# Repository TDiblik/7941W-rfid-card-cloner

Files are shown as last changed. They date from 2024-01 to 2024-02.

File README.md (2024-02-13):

# RFID Card Cloning Device

- [Showcase](#showcase)
- [Prerequisites](#prerequisites)
- [What HW do I need?](#what-hw-do-i-need)
- [How does it work?](#how-does-it-work)
  - [After turning the device on](#after-turning-the-device-on)
  - [S mode](#s-mode)
  - [Z mode](#z-mode)
- [How to setup?](#how-to-setup)
- [Bitmap generator](#bitmap-generator)
- [Development notes](#development-notes)
- [Legal notice](#legal-notice)

# Showcase

Showcase gif

# Prerequisites

- Whenever the docs call something "a/the display", it means the 8x8 LED matrix
- Whenever the docs say "input", it means the Joystick, or selecting something with the Joystick
- Whenever the docs say "the menu", it means the 6 options (S1, S2, S3, Z1, Z2, Z3)
- Whenever the docs call something "a/the board", it means XIAO nRF52840
- The cloner supports 2 types of cards: 125KHz and 13.56MHz.
  - When referring to both, the docs say "type 1"
  - 125KHz is refferd to as "type 2"
  - 13.56MHz is refferd to as "type 3"
- All actions are tried **5 times** before failing. If you wish to change this behaviour, you can do so by changing `NUMBER_OF_EXECUTE_RETRIES` inside `./advanced/src/Menu.h`
- Code for the actual device is inside the `./advanced` folder and the resources for it are inside the `./resources` folder.
  - There is also the `./simple` folder. This was simply a test of mine (fully functional tho) before creating the final devices, to make sure that the 7941W is working as expected. If you want to just clone cards at home, wire it based on the `./simple/wiring.jpg` and upload the code using Platformio VSCode.

# What HW do I need?

1. Seeed Studio XIAO nRF52840
2. 7941W dual-frequency reader-writer
3. A Joystick
4. Adafruit Mini 8x8 LED Matrix w/I2C Backpack
5. A ON/OFF switch
6. 4 AAA battery case
7. Clear, writeable 125KHz (usually labeled EM4305/T5577) and 13.56MHz cards (for example Mifare 1k S50)

# How does it work?

Wire schematic<br/>
The heart component that allows this to work is the `7941W Dual-Frequency Card Reader/Writer`, which is controlled by the board using [the manufacturer's protocol over UART](https://www.icstation.com/dual-frequency-rfid-reader-writer-wireless-module-uart-1356mhz-125khz-icid-card-p-12444.html). <!-- I was unable to find docs, and the website I linked was used as a reference during the development --> This component does the whole "reading an ID" and "writing an ID" part of the device. <br />
However, as a user, you don't really care about that. (if you indeed care more about that tho, browse the source code, it's not that complicated `cat src/* | wc -l => 788`) <br />

## After turning the device on

If you're running in DEBUG mode (variable `DEBUG` inside `./advanced/src/debug.h` is set to `true` at the time of compilation), you will **skip** the initial animation where two images appear on the display for 1.5s (both):

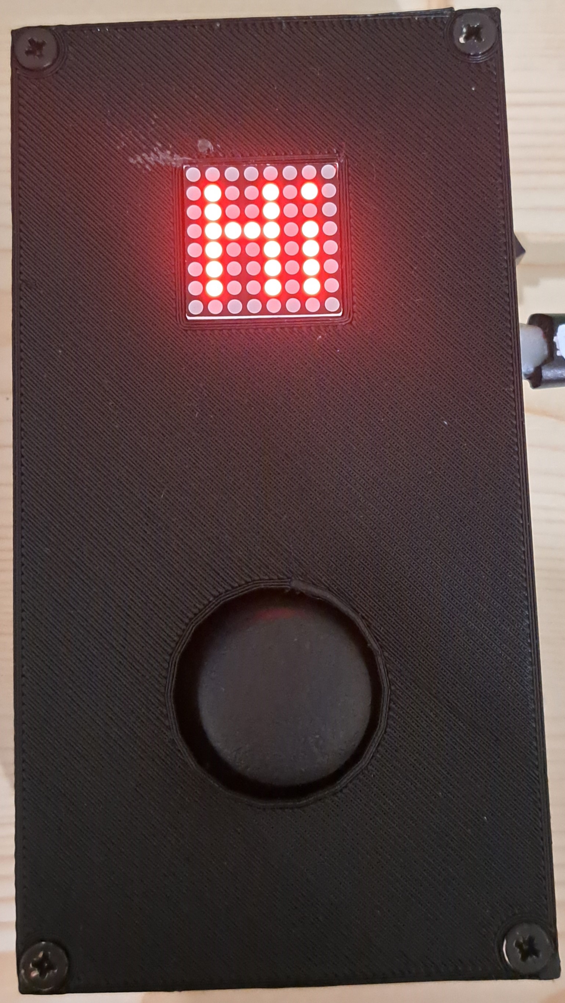
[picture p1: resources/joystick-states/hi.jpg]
Jostick state with HI written on the display

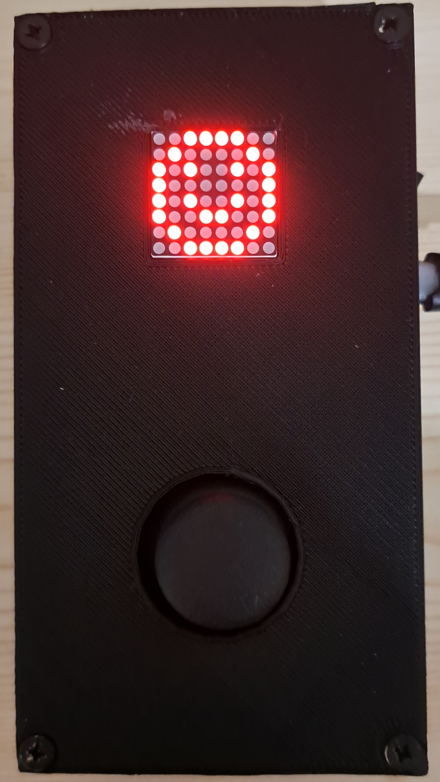
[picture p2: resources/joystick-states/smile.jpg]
Jostick state with smiley face on the display


After that, you will be put into the menu. This is the only way to control the device.
There are two main "modes". The S mode and Z mode. Both have 3 options. You can switch between the options and modes using the joystick (UP and DOWN movements) [if you're confused about the wiring, consult `./advanced/src/Joystick.cpp`].

## S mode

This mode is used for scanning cards. You can choose from one of 3 options (S1, S2, S3). <br/>
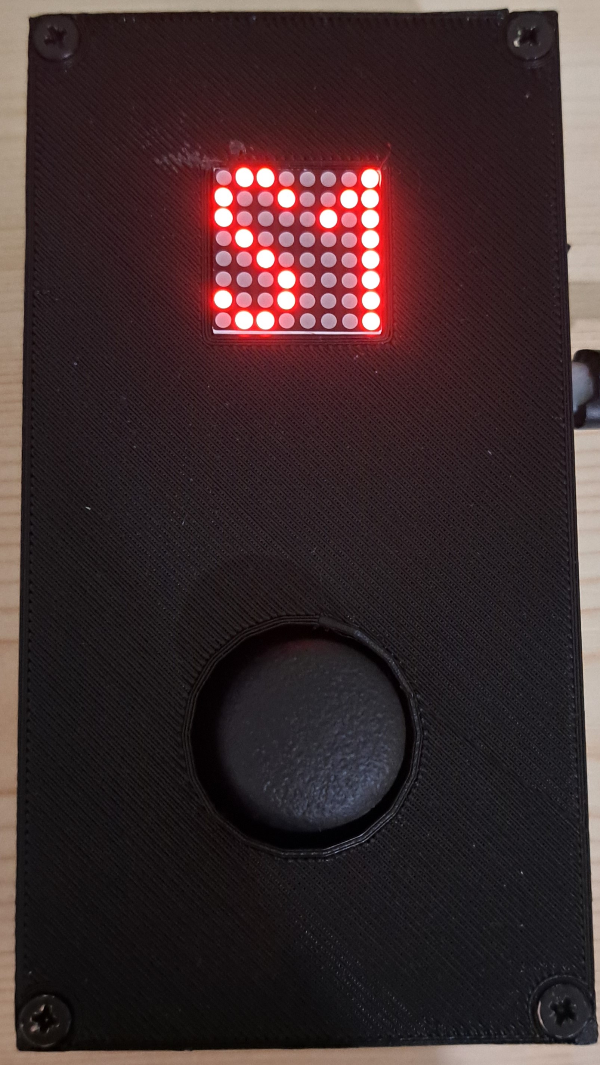
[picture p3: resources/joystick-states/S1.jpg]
Jostick state with S1 option selected

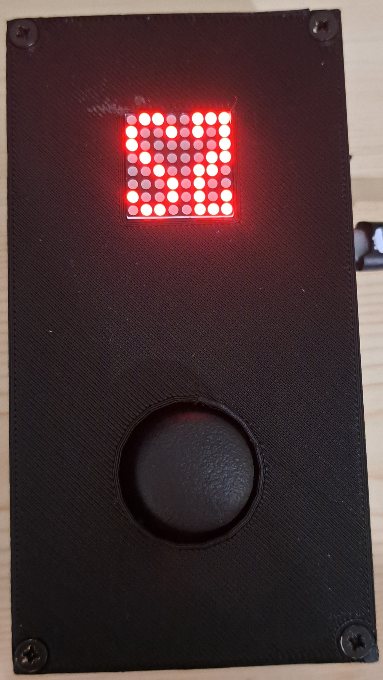
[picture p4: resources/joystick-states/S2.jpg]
Jostick state with S2 option selected

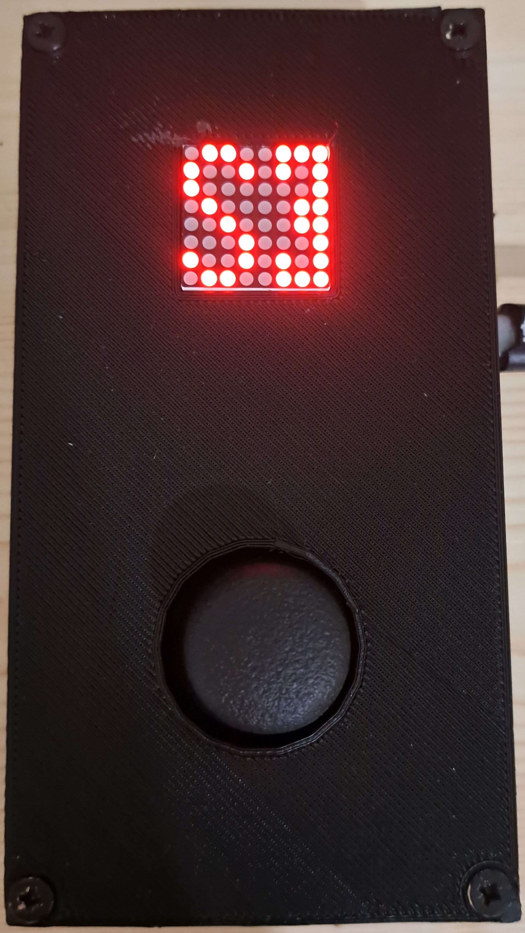
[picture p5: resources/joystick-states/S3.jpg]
Jostick state with S3 option selected
 <br/>
After you've selected the desired mode, place the card near the scanner (back of the device) and press down on the joystick. When the S mode succeeds, the card is remembered in RAM. When the S mode fails, nothing happens. The last remembered card is **always** the last successful scan result. After a successful scan, the result of the scan (image drawn to the display) stays there until a new input is registered. <br/>
As mentioned before, there are 3 options: <br/>

- S1: This mode works as S2 and S3 combined. It scans for both types of cards and then shows the results. Because of that, it has special success results. Other results are the same as for the S2 and S3 options (+ the number for which the result applies is shown after the result).
- S2: This mode scans only for the type 2 cards.
- S3: This mode scans only for the type 3 cards.

After each scan, there is a result shown. If the result **is not a Failure**, then the information (even if partial), gets stored in the device RAM. Even after a partial success (see below), you can still proceed to write this information onto your blank card (however it's probable that it won't work as expected). The results for **S2** and **S3** are as follows:

**Success:**
Everything went according to the plan: <br/>
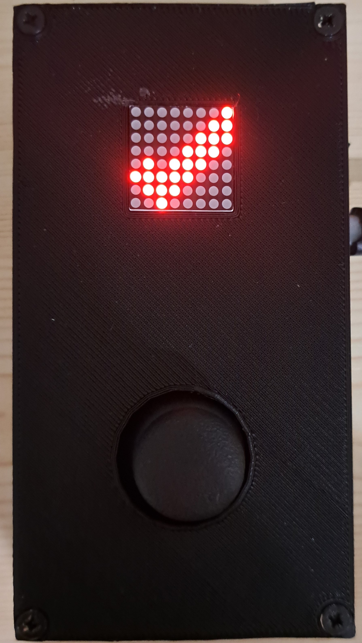
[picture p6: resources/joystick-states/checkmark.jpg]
Jostick state with checkmark on the display
 <br/>

**Undefined Response:**
There were errors while communicating with the cloning device. This can (for example) occur when there is not enough time for the card to be scanned: <br/>
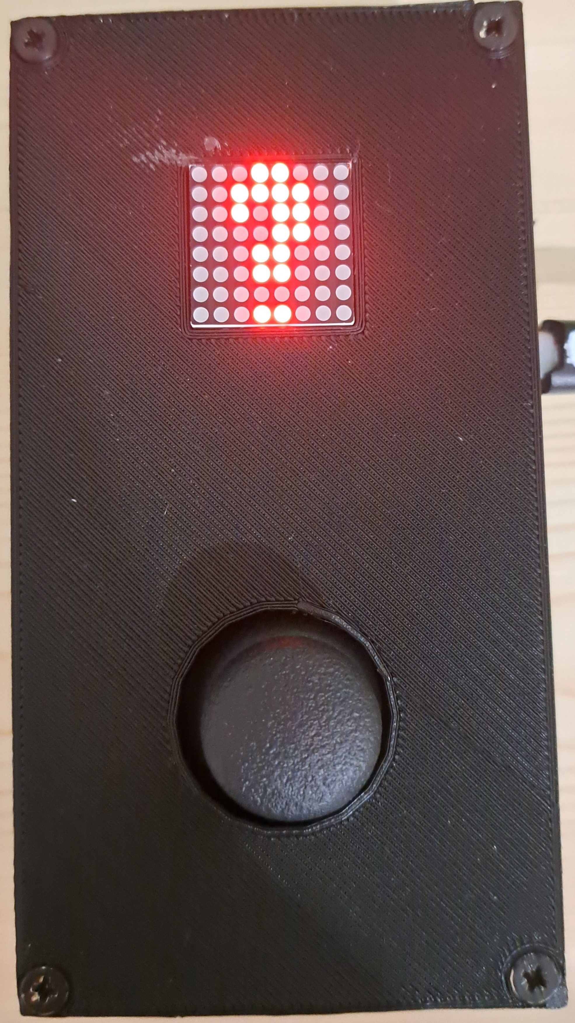
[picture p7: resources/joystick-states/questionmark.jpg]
Jostick state with questionmark on the display
 <br/>

**Invalid Checksum:**
The device sent back an ID, **however** the checksum of the message sent does not match the checksum calculated. This usually means that one or two of the bits of the ID received are not correct and there may have been some interference while receiving the data: <br/>
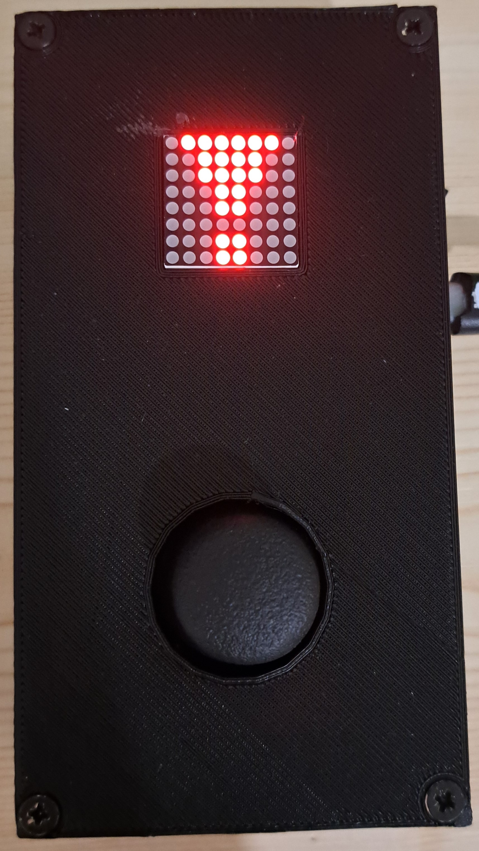
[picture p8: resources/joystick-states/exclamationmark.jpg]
Jostick state with exclamationmark on the display
 <br/>

**Failure:**
The action failed. Nothing is stored into the RAM. This can occur when there is no supported card to be read. <br/>
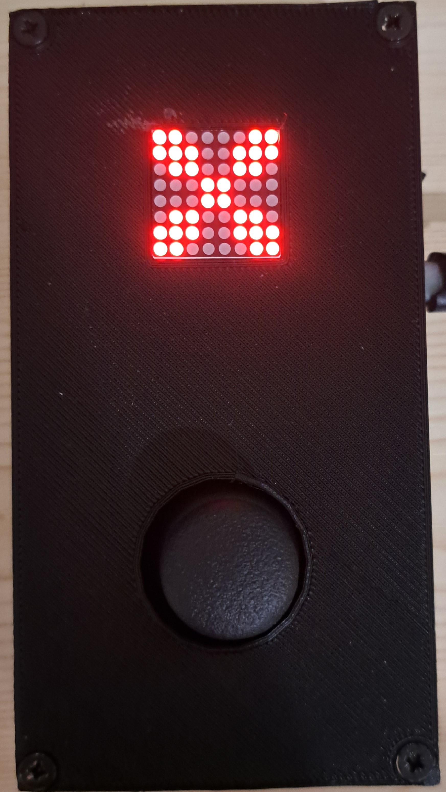
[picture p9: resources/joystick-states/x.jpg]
Jostick state with an X on the display
 <br/>

**S1 Success (type 1):** <br />
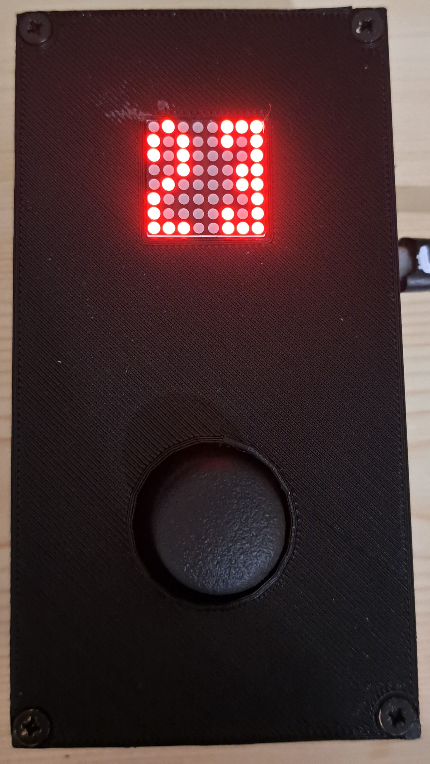
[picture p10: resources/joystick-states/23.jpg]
Jostick state with 23 written on the display
Jostick state with checkmark on the display <br />
Both the type 2 and type 3 cards were found and scanned. This can happen when one card supports multiple frequencies, or when multiple cards were placed near the scanner.

**S1 Success (type 2):** <br />
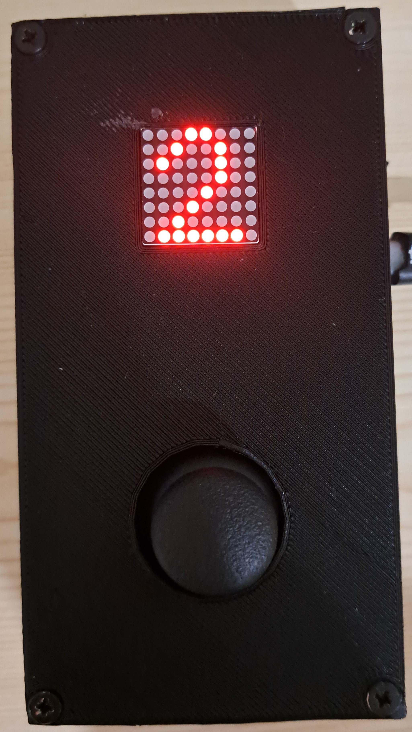
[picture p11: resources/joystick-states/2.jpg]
Jostick state with 2 written on the display
Jostick state with checkmark on the display <br />

**S1 Success (type 3):** <br />
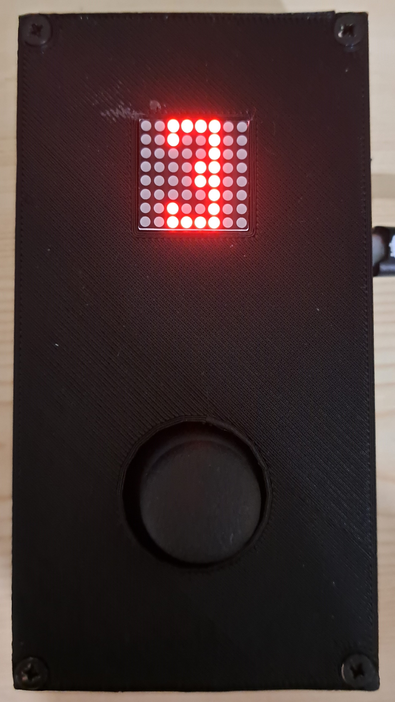
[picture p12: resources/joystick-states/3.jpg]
Jostick state with 3 written on the display
Jostick state with checkmark on the display <br />

## Z mode

This mode is used for writing scanned cards. You can choose from one of 3 options (Z1, Z2, Z3). <br/>
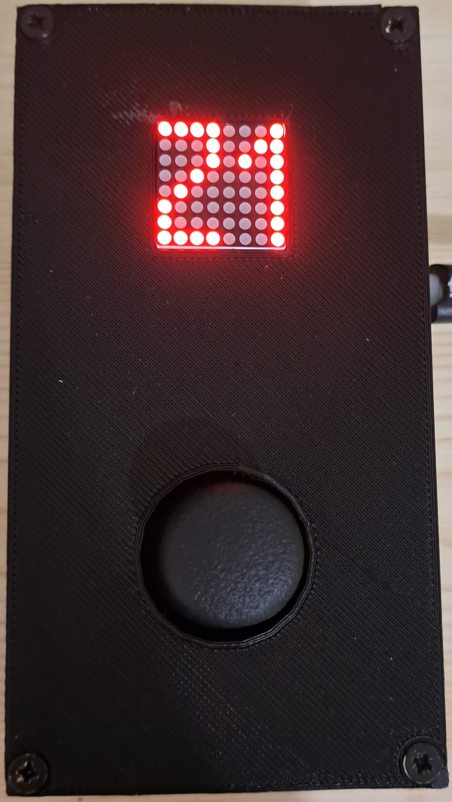
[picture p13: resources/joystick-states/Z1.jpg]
Jostick state with Z1 option selected

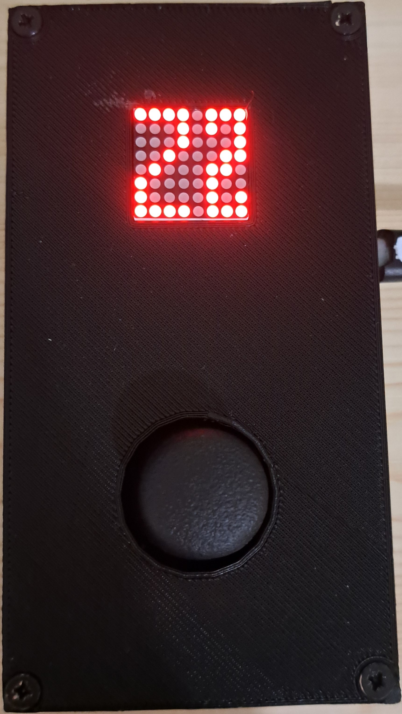
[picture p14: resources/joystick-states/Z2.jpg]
Jostick state with Z2 option selected

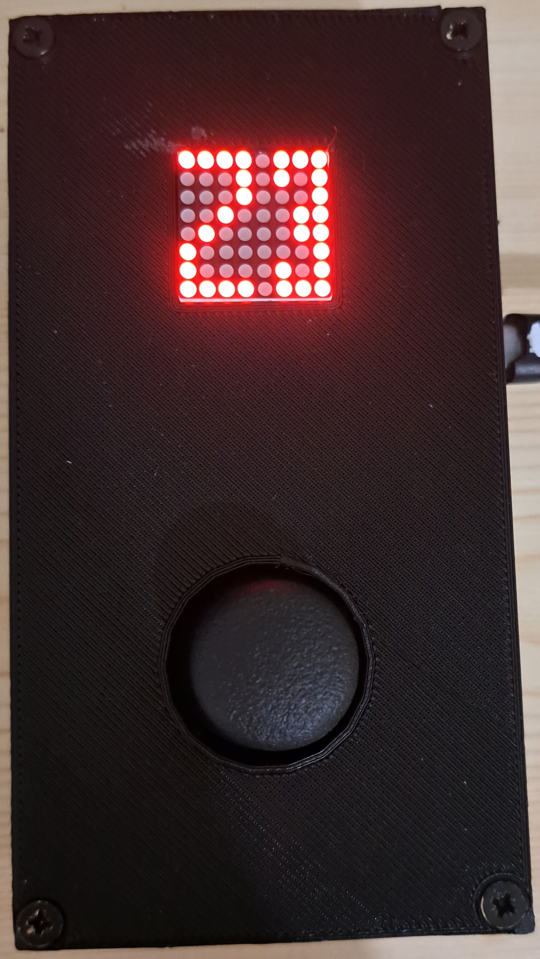
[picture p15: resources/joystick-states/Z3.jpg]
Jostick state with Z3 option selected
 <br/>
After you've read a card, you want to "clone it" onto your clear card. That's what these 3 modes are for. After you've selected one of the modes and pressed onto the joystick, there will be an action performed (based on the selection): <br/>

- Z1: This mode works as Z2 and Z3 combined. It tries to write onto both types of cards and then shows the results. Because of that, it has special success results. Other results are the same as for the Z2 and Z3 options.
- Z2: This mode tries to write onto the type 2 cards.
- Z3: This mode tries to write onto the type 3 cards.

Since the typical responses (Success, Undefined response, Invalid checksum, Failure,...) are the same for Z modes (and have the same implications, just replace "read" with "write" while reading them) as for the S modes, they are not included here. If you see them after using the Z mode, just consult the docs part above. <br/>
What is different, however, are the Z1 responses. After you try to write using Z1, there is always a type number flashed and the appropriate response for the card type (for example: "2 flashes with Failure and then 3 flashes with Success" -> This means that the device was unable to write onto type 2 card, however, it was able to write onto the type 3 card)
If you were to try to write before scanning any card, the following symbol will be shown, indicating that there is no card stored in the RAM. <br/>
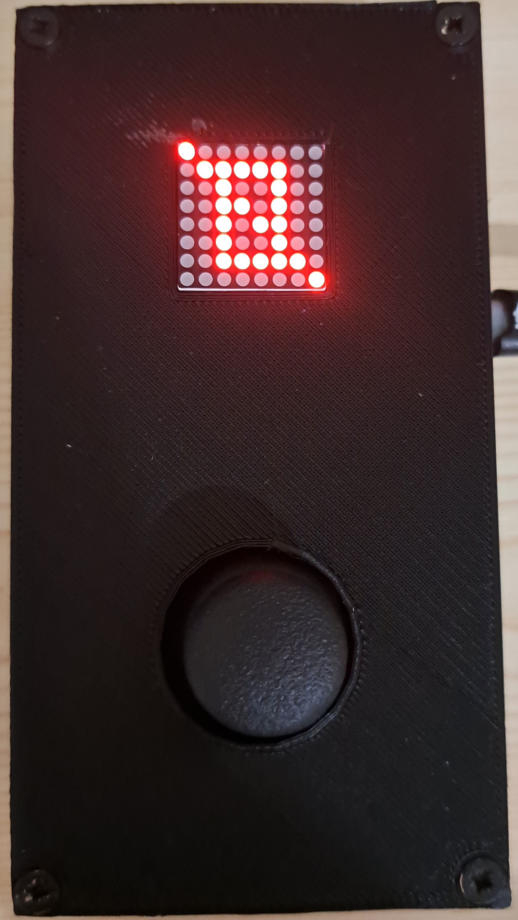
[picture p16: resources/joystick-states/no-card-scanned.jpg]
Jostick state with no-card-scanned symbol on the display


# How to setup?

1. Somehow connect the wires according to the schematic
2. Write a new version of the firmware onto the device (using Platformio and VSCode)
3. 3D print the case using the exported files provided `./resources/case-export` or edit/export them on your own with FreeCAD `./resources/case.FCStd`
4. Put electronics into the case
   - for the insides, use +-1.5mm radius screws
   - the battery holder should be placed in the lower part of the back case such that you can replace them from the other side.
   - 7941W should be screwed onto the two columns inside the "back part" of the case.
   - board should be placed onto the "holder" right above the 7941W and pointing outwards by the USB-C port.
   - you can probably guess how to screw in the joystick and display based on the design of the "top part" of the case.
5. Screw the case together (use at most 3mm radius screws)
6. Enjoy your device :)
7. If you find a bug, or have a problem with anything SW/HW related, [open an issue](https://github.com/TDiblik/7941W-rfid-card-cloner/issues), or shoot me an email

# Bitmap generator

You might notice, in the root of the project, there is a Python script called `bitmap_generator.py`. You can use this to generate bitmaps to draw onto the display. All you have to do is start the program `python bitmap_generator.py`. The following window will pop up: <br/>
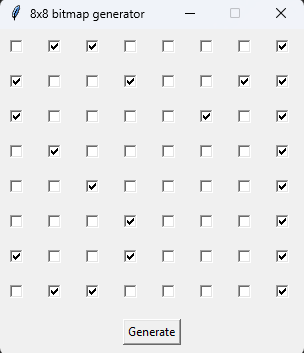
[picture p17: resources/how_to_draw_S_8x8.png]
Example usage of the bitmap generator to draw S1
 <br/>
Here, you can draw something that you want to get displayed on the screen. After you're done, hit the "Generate" button. This will output "C code" that you can put into the project. The output will look like this:

```cpp
static const uint8_t PROGMEM NAME_BITMAP[]
{ 0b01100001,
  0b10010011,
  0b10000101,
  0b01000001,
  0b00100001,
  0b00010001,
  0b10010001,
  0b01100001 };
```

If you pass this as an argument into the `LEDMatrix.draw` or `LEDMatrix.blink` functions, it will get drawn. You can quickly test it out by changing the `main.cpp` to the following:

```cpp
#include <Arduino.h>
#include <Wire.h>
#include <SPI.h>

#include "debug.h"
#include "LEDMatrix.h"

static LEDMatrix led_matrix = LEDMatrix();

// REPLACE THIS WITH YOUR GENERATED BITMAP
static const uint8_t PROGMEM YOUR_GENERATED_BITMAP[]
{ 0b00000000,
  0b01001010,
  0b01001000,
  0b01111010,
  0b01001010,
  0b01001010,
  0b01001010,
  0b00000000 };

void setup() {
  Serial.begin(9600);
  led_matrix.setup();
  debug_println("LED Matrix - done");
}

void loop() {
  led_matrix.draw(YOUR_GENERATED_BITMAP);
  delay(500); // we don't want to spam it... Tbh, the `.draw` could be in the setup function and the loop could be empty
}
```

# Development notes

1. Before pushing a release version of the firmware, make sure to change the `DEBUG` variable inside `./advanced/src/debug.h` to `false` at the time of compilation.
2. As a convention, all bitmaps are stored inside the `./advanced/src/LEDMatrix.h` and named in UPPERCASE.

# Legal notice

The code/device/files (further addressed as just "device") provided are for educational purposes only and should not be used for any malicious or illegal activities. Any unauthorized use of this device is strictly prohibited and violators will be held liable for their actions. The device is intended to be used solely for the purpose of learning and understanding vulnerabilities and should not be executed on any systems without proper authorization and oversight. The author of this device takes no responsibility for any actions taken by any party using this device and is not liable for any damages or harm caused as a result of its use.

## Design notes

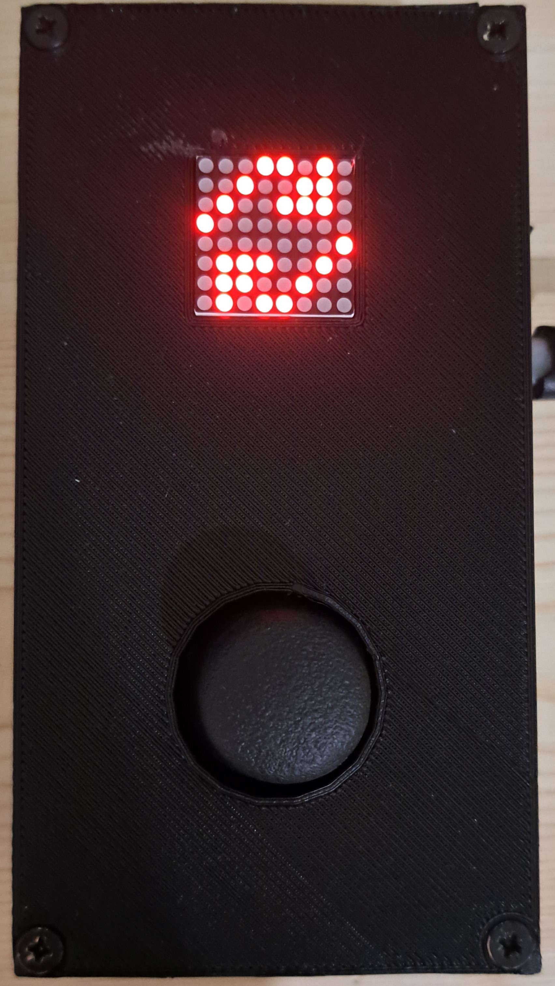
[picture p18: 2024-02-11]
resources/joystick-states/loading.jpg

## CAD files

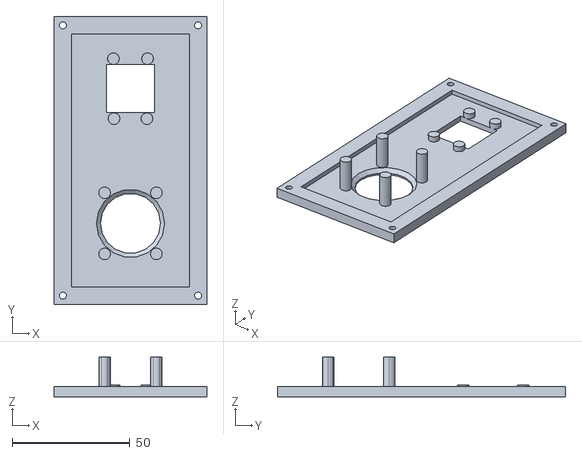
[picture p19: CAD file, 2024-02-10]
resources/case-export/front.obj
65.0 x 122.5 x 17.0

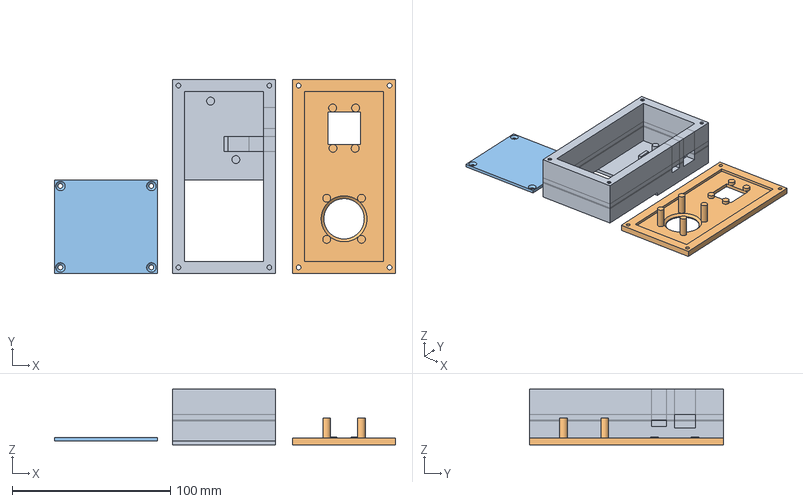
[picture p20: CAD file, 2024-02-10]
resources/case.FCStd
215.6 x 122.5 x 35.4 mm
back
front
closing

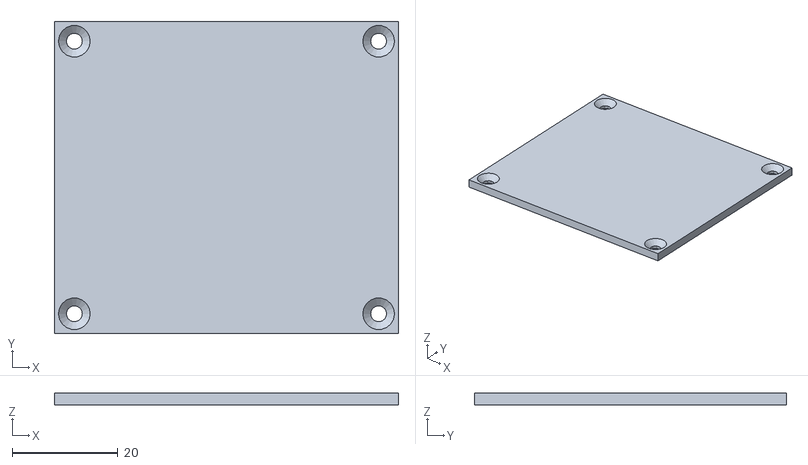
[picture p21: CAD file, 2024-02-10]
resources/case-export/closing.obj
65.0 x 59.0 x 2.25

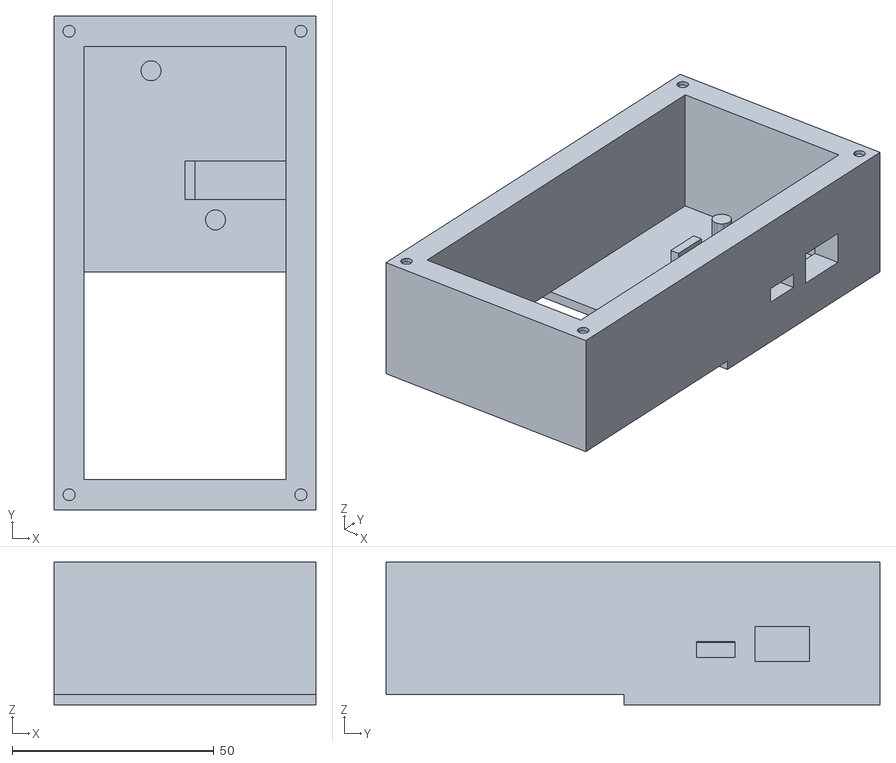
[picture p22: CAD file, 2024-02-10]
resources/case-export/back.obj
65.0 x 122.5 x 35.4

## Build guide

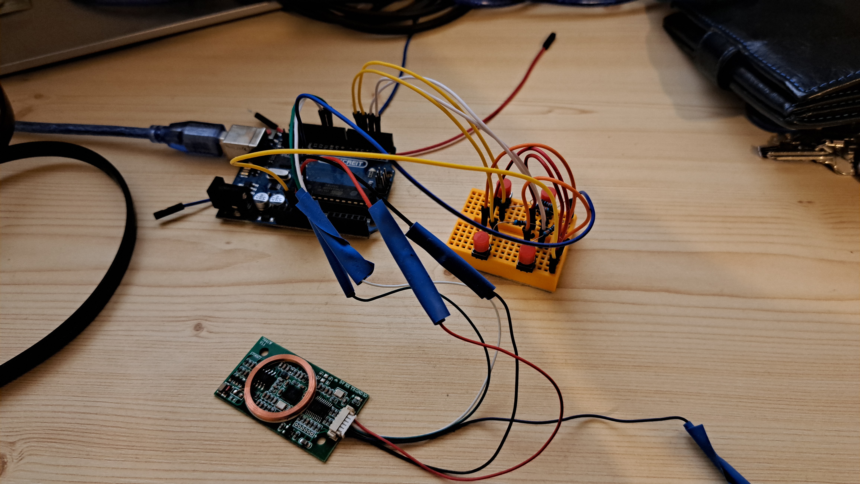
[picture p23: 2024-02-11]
simple/wiring.jpg

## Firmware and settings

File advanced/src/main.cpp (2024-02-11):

#include <Arduino.h>
#include <Wire.h>
#include <SPI.h>

#include "debug.h"
#include "Joystick.h"
#include "LEDMatrix.h"
#include "Menu.h"
#include "RFID.h"

static Joystick joystick = Joystick(D0, A1, A2);
static LEDMatrix led_matrix = LEDMatrix();
static RFID rfid = RFID(Serial1); // Connect RFID-RX->Board-D6 ; RFID-TX->Board-D7, refers to https://files.seeedstudio.com/wiki/XIAO-BLE/pinout2.png
static Menu menu = Menu(led_matrix, rfid);

void setup() {
  Serial.begin(9600); // always try to establish a connection (even in release mode), it's easier to flash new versions / diagnose errors this way

  debug_println("--- Setting up HW components ---");
  delay(500); // wait for a bit, just to make sure

  joystick.setup();
  debug_println("Joystick - done");

  led_matrix.setup();
  debug_println("LED Matrix - done");

  rfid.setup();
  debug_println("Communication with the cloner - done");

  debug_println("--- Finished setup successfully ---");
}

void loop() {
  menu.handle_input(joystick.get_status());
}

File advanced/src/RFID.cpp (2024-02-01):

#include "RFID.h"
#include "debug.h"

void RFID::setup() {
    this->_serial.begin(115200);
}

RFIDReadResult* RFID::read_id_125KHz() { return this->_read_id((uint8_t)0x15); };
RFIDReadResult* RFID::read_id_1356MHz() { return this->_read_id((uint8_t)0x10); };
RFIDResponse RFID::write_id_125KHz(RFIDReadResult* card_info) { return this->_write_id((uint8_t)0x16, card_info); };
RFIDResponse RFID::write_id_1356MHz(RFIDReadResult* card_info) { return this->_write_id((uint8_t)0x11, card_info); };

RFIDResponse RFID::_read_rw_response_into_buf() {
    // Cleanup before reading
    for (uint16_t i = 0; i < MAX_POSSIBLE_RW_RESPONSE_LEN; i++) {
        this->__rw_response_buf[i] = 0;
    }
    this->_serial.flush();

    // Read everything
    delay(200);
    uint16_t i = 0;
    while ((this->_serial.available() > 0) && (i < MAX_POSSIBLE_RW_RESPONSE_LEN)) {
        this->__rw_response_buf[i++] = this->_serial.read();
        delay(100);
    }
    this->__rw_response_buf_len = i;

    // This should get optimized away by the compiler when DEBUG == false
    debug_print("Response: ");
    for (i = 0; i < this->__rw_response_buf_len; i++) {
        debug_print_hex(this->__rw_response_buf[i]);
        debug_print(" ");
    }
    debug_println("");

    if (this->__rw_response_buf_len < 3) {
        return RFIDResponse::UndefinedResponse;
    }

    switch (this->__rw_response_buf[3]) { // forth byte is always the response status code
    case 0x81:
        return RFIDResponse::Success;
    case 0x80:
        return RFIDResponse::Failure;
    default:
        return RFIDResponse::UndefinedResponse;
    }
}

// Format of the RFID reponse
// CD DC               0           81             5           x x x x x       X
//   ^                 ^           ^              ^               ^           ^
// protocol header   address   status code   response len   the id bytes   bytes checksum
RFIDReadResult* RFID::_read_id(uint8_t command) {
    this->_serial.write((uint8_t)0xAB);  // protocol header
    this->_serial.write((uint8_t)0xBA);  // protocol header
    this->_serial.write((uint8_t)0x00);  // address
    this->_serial.write(command);        // command
    this->_serial.write((uint8_t)0x00);  // data length
    this->_serial.write(command);        // XOR checksum (in this case always equal to the command, no need to calculate)

    RFIDReadResult* result = new RFIDReadResult();

    RFIDResponse response = this->_read_rw_response_into_buf();
    result->status = response;
    if (response != RFIDResponse::Success) {
        return result;
    }

    uint8_t response_id_length = this->__rw_response_buf[READ_ID_RESPONSE_OFFSET - 1];
    uint8_t response_id_end_index = READ_ID_RESPONSE_OFFSET + response_id_length - 1;
    uint8_t response_checksum = this->__rw_response_buf[READ_ID_RESPONSE_OFFSET + response_id_length];

    //                                  address           ^       status code       ^ response_len
    uint8_t calculated_checksum = this->__rw_response_buf[2] ^ this->__rw_response_buf[3] ^ response_id_length;

    uint8_t* reponse_id = new uint8_t[response_id_length];
    for (uint8_t i = READ_ID_RESPONSE_OFFSET; i <= response_id_end_index; i++) {
        uint8_t current_id_byte = this->__rw_response_buf[i];
        reponse_id[i - READ_ID_RESPONSE_OFFSET] = current_id_byte;
        calculated_checksum ^= current_id_byte;
    }
    result->id = reponse_id;
    result->id_length = response_id_length;

    if (response_checksum != calculated_checksum) {
        result->status = RFIDResponse::InvalidChecksum;
    }
    return result;
}

RFIDResponse RFID::_write_id(uint8_t command, RFIDReadResult* card_info) {
    if (card_info == nullptr || card_info->status == RFIDResponse::Failure || card_info->id_length < 1) {
        return RFIDResponse::NoCardProvidedToWriteFunction;
    }

    // Prepare checksum
    uint8_t checksum = 0x00 ^ command ^ card_info->id_length;

    // Send the command
    this->_serial.write((uint8_t)0xAB);         // protocol header
    this->_serial.write((uint8_t)0xBA);         // protocol header
    this->_serial.write((uint8_t)0x00);         // address
    this->_serial.write(command);               // command
    this->_serial.write(card_info->id_length);  // data length
    for (uint8_t i = 0; i < card_info->id_length; i++) {
        uint8_t current_byte = card_info->id[i];
        this->_serial.write(current_byte);
        checksum ^= current_byte;
    }
    this->_serial.write(checksum);              // XOR checksum

    return this->_read_rw_response_into_buf();

}

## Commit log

2023-10-11 [Feature] Write onto both types of chips
    Also, check checksum after reading and bump up read times to prevent unnecessary error
    [main.cpp, utils.cpp]
2024-01-29 [Wip] Advanced version of the cloning device
2024-01-31 [Feature] S1 working + fixing some memory leaks
    [RFID.cpp]
2024-02-01 [Fix] Scratch the sector R/W functionality
    [RFID.cpp]
2024-02-02 [Feature] circuit diagrams
2024-02-03 [Wip] 3D Model case
    [case.FCStd]
2024-02-06 [Feature] Finalize case design
    [case.FCStd]
2024-02-08 [Fix] Minor changes to the battery closing lid
    [case.FCStd]
2024-02-10 [Fix] Forgot screw top on top of one hole
    [back.obj, case.FCStd, closing.obj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]
2024-02-10 [Fix] Change X and D pins because I soldered it incorrectlly xdd
2024-02-11 [Docs] Add resources for both versions of the cloning device
2024-02-14 [Fix] The wire schematic should include the ON/OFF switch
